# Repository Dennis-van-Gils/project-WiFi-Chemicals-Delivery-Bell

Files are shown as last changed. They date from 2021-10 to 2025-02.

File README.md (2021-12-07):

# WiFi Chemicals Delivery Bell

This project concerns an automated delivery notification system for when chemicals get delivered to our laboratory. Simply put, it is a box containing two huge arcade buttons which should get pressed by the deliverer: One for regular chemicals, and the other for temperature-critical (cooled) chemicals. All the deliverer has to do is push the appropriate button when having delivered chemicals. Once pushed, the buttons will light up and an email will be send to a configurable mailing list to inform everyone that chemicals are awaiting. There is also a web interface showing the current status, which you could check on your smartphone for instance. The buttons can be reset by pressing them again. This will revert the status to 'No chemicals awaiting' once more. 

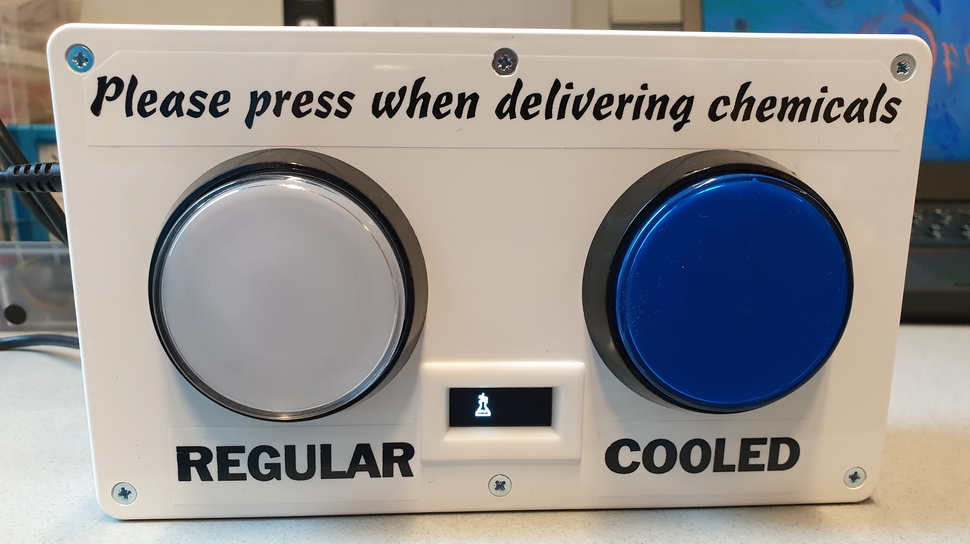
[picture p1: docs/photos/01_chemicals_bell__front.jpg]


The `Bell` is powered by a WiFi-enabled microprocessor board from Adafruit, namely an [Adafruit Feather HUZZAH ESP8266](https://www.adafruit.com/product/3046). This board sends out the button status over WiFi to a web server hosting the web interface. The web server also takes care of the emailing. An handy OLED screen on the `Bell` shows information regarding the WiFi connectivity, possible network errors, or when all is fine, an animation to inform the user about what it is doing. A 'flask' symbol indicates a happy idle state and an 'email' symbol indicates that an email will be send out within the coming minute. Repeatedly pressing the buttons will not cause massive email spam as there is this delay of one minute.

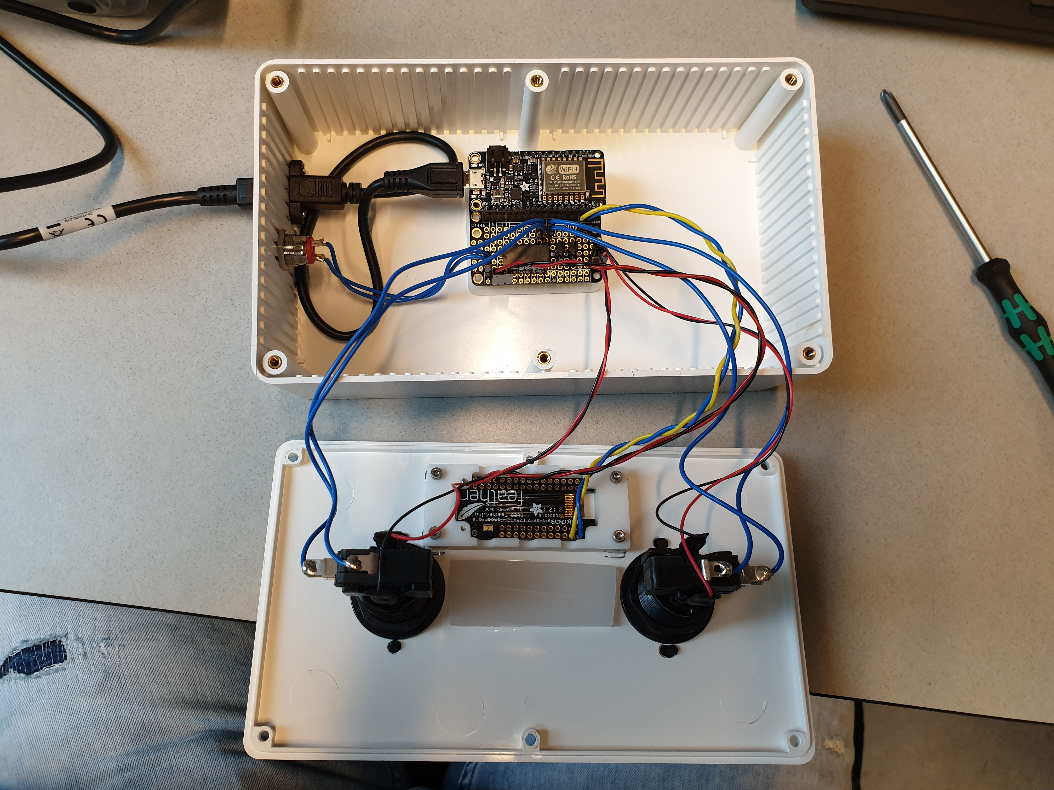
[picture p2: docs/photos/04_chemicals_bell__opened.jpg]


Detailed plans are included to build one yourself. The total parts cost of the enclosure plus electronics is around €130. The shopping lists are included (see below). A small amount of soldering is required. A few parts have to be 3D-printed, namely the OLED screen holder and the microcontroller board mounting plate (STL files included), but you could also [MacGyver](https://www.bbc.com/news/magazine-34075407) your own construction here.

I will gladly assist my colleagues at the University if they want to go live with the `Bell`. Setting up the web server is straight-forward. Simply copy the `web` folder to your server (presumably, the server that already is hosting your group's internet page) and edit the single configuration file `globals.php` to set up the email list and the hashed password used between the microcontroller and the server. The microcontroller itself needs to be flashed with firmware which has to be compiled. The source code for this is included in folder `source_mcu` and it has one configuration file you should edit: `source_mcu/src/wifi_settings_template.h`. If you send me your configuration file, I can also easily compile the firmware for you. 

Specific to the University of Twente: Each WiFi microcontroller has a unique MAC address which has to get registrered by LISA in order to get access to the Internet-of-Things network of the University. The microcontroller itself is firewalled by LISA from any incoming traffic.

## Web interface

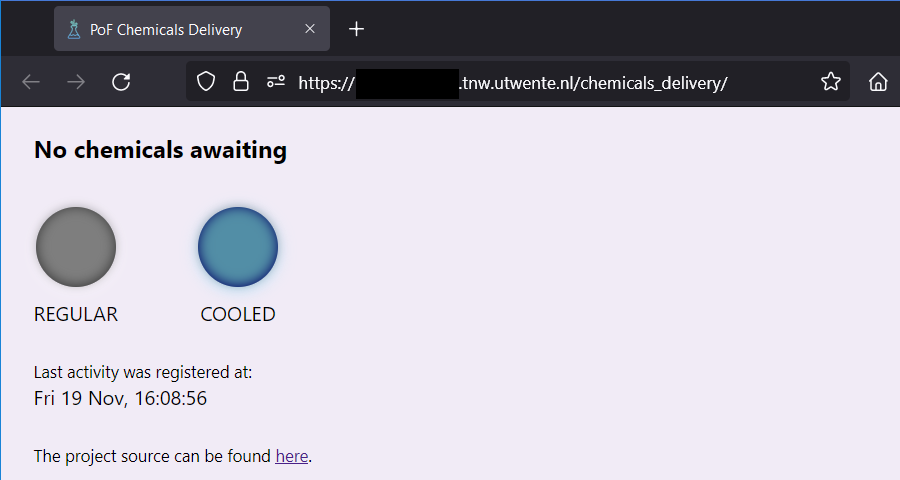
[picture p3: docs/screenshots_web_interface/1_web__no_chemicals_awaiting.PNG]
Web interface

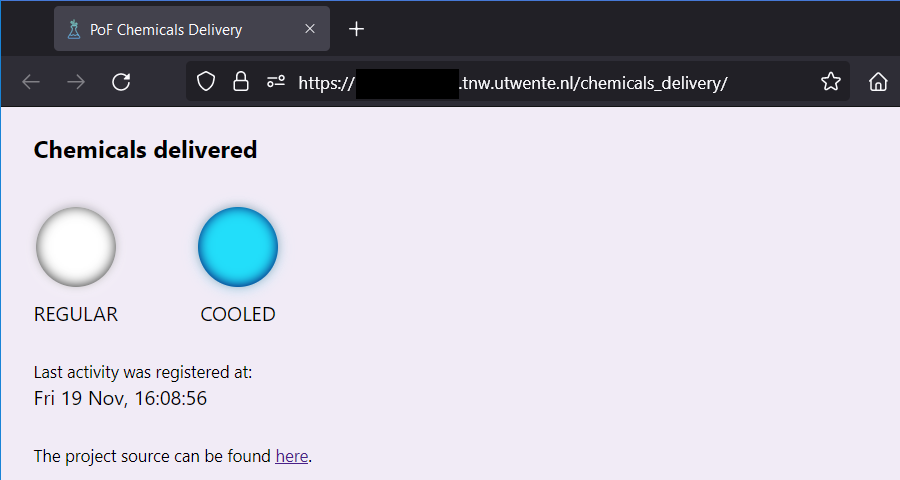
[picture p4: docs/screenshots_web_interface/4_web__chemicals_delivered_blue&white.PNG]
Web interface


## Design

[Solidworks 3D PDF](/Solidworks/_WiFi_Chemicals_Delivery_Bell.pdf)

[Electronic diagram](/docs/electronics/electronic_diagram.pdf)

## Soldering templates

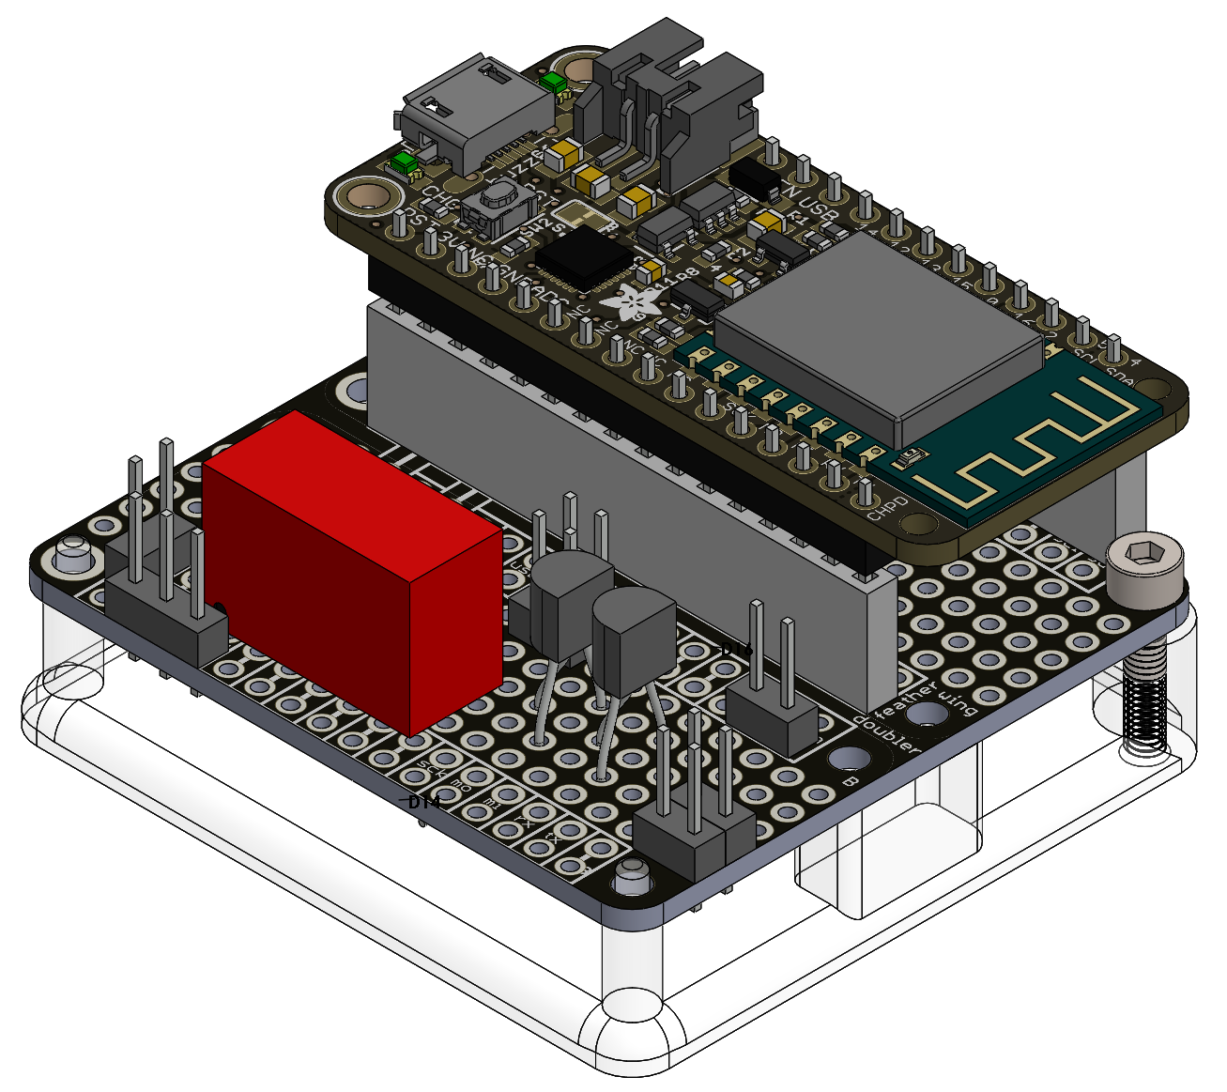
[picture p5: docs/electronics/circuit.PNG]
Soldering template 3D

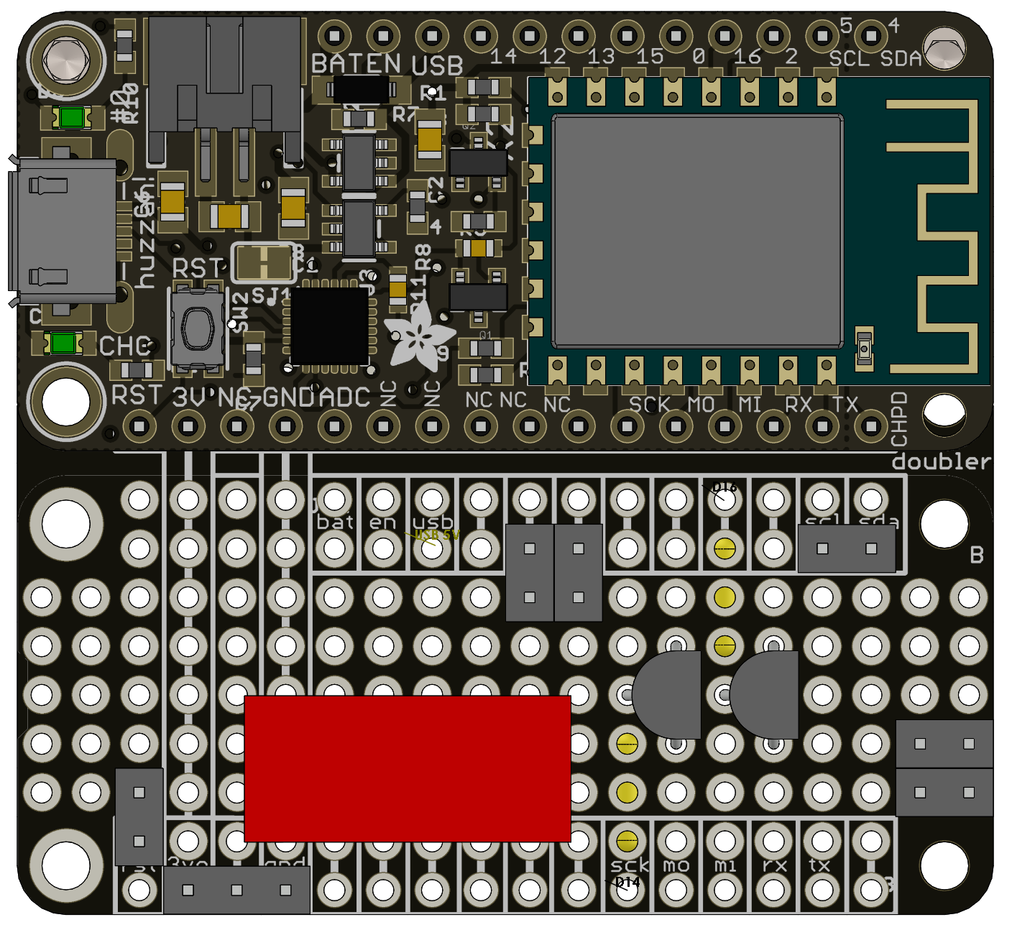
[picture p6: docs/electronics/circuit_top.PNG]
Soldering template top

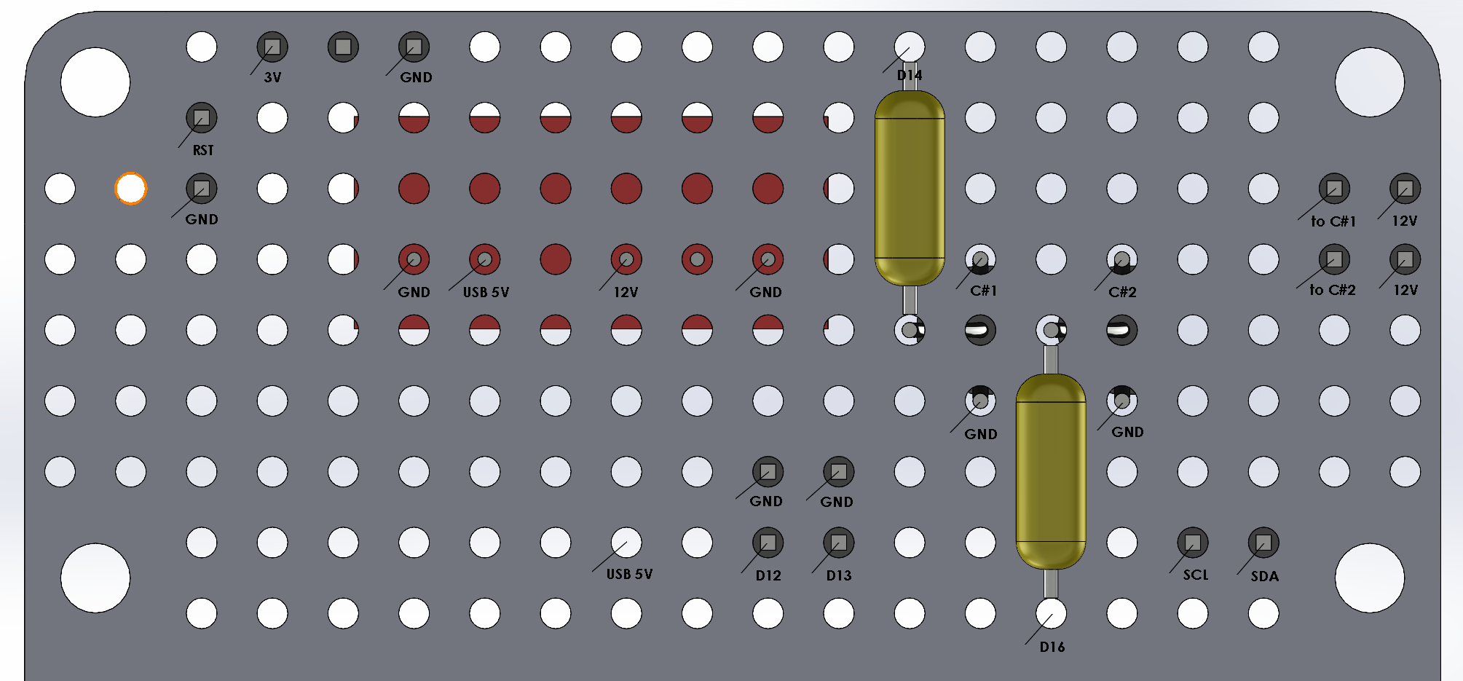
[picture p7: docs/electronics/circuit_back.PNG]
Soldering template back

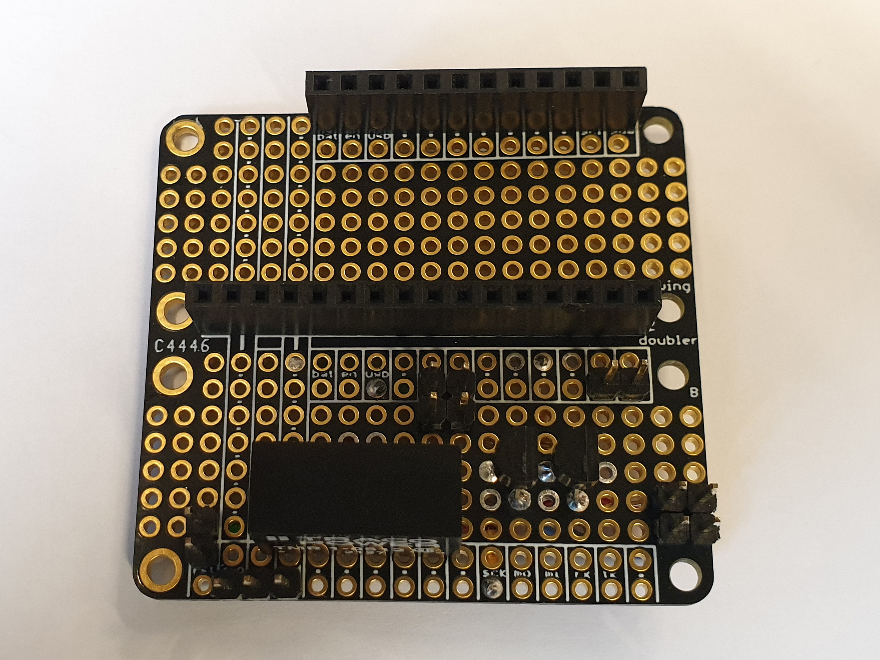
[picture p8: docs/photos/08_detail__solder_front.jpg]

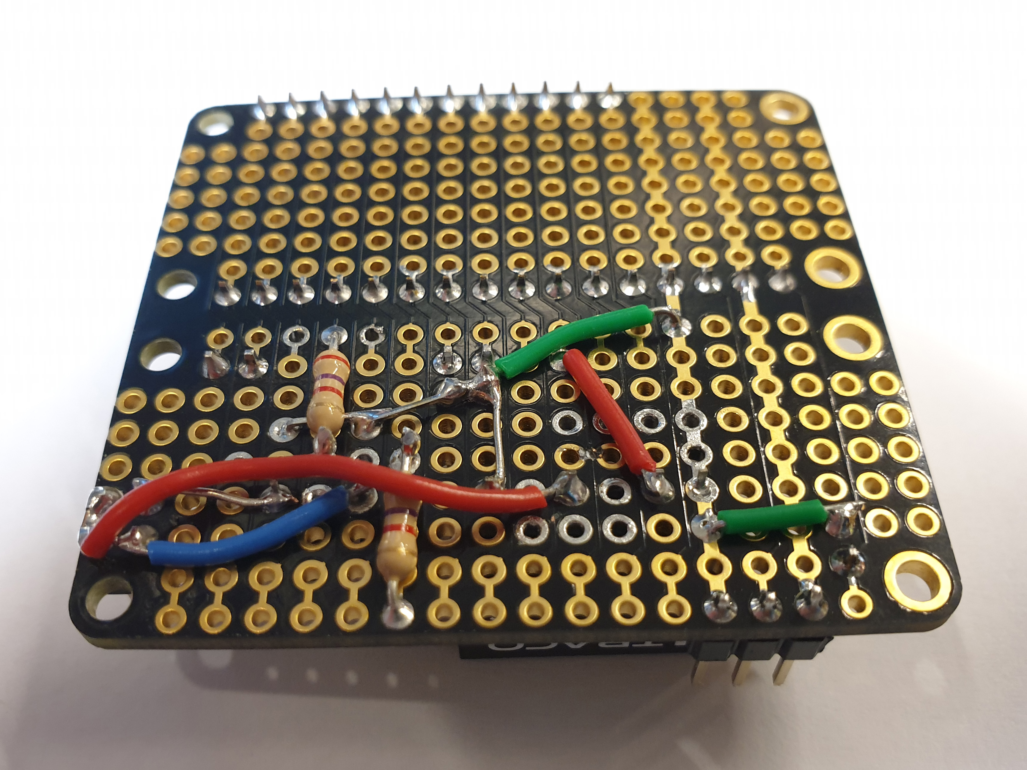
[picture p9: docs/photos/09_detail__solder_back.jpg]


## Shopping cart

[Shopping cart Farnell](/docs/shopping/_shopping_cart_Farnell.pdf)

[Shopping cart Kiwi Electronics](/docs/shopping/_shopping_cart_Kiwi_Electronics.pdf)

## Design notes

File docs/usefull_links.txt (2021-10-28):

CSS LED Lights                                                            https://codepen.io/fskirschbaum/pen/MYJNaj

How To HTTP GET and POST requests with ESP8266 - ESP8266 Shop             https://esp8266-shop.com/blog/how-to-http-get-and-post-requests-with-esp8266/

The Smallest WiFi Button in the World (ESP8266, MQTT, IFTTT) - YouTube    https://www.youtube.com/watch?v=ImVK5cGVrpQ

web page hot reload in plain JavaScript + Apache & PHP ← ABrandao.com     http://www.abrandao.com/2019/04/web-page-hot-reload-in-plain-javascript-php/

https://randomnerdtutorials.com/esp8266-nodemcu-http-get-post-arduino/
https://forum.arduino.cc/t/esp8266-httpclient-library-for-https/495245
https://maakbaas.com/esp8266-iot-framework/logs/https-requests/

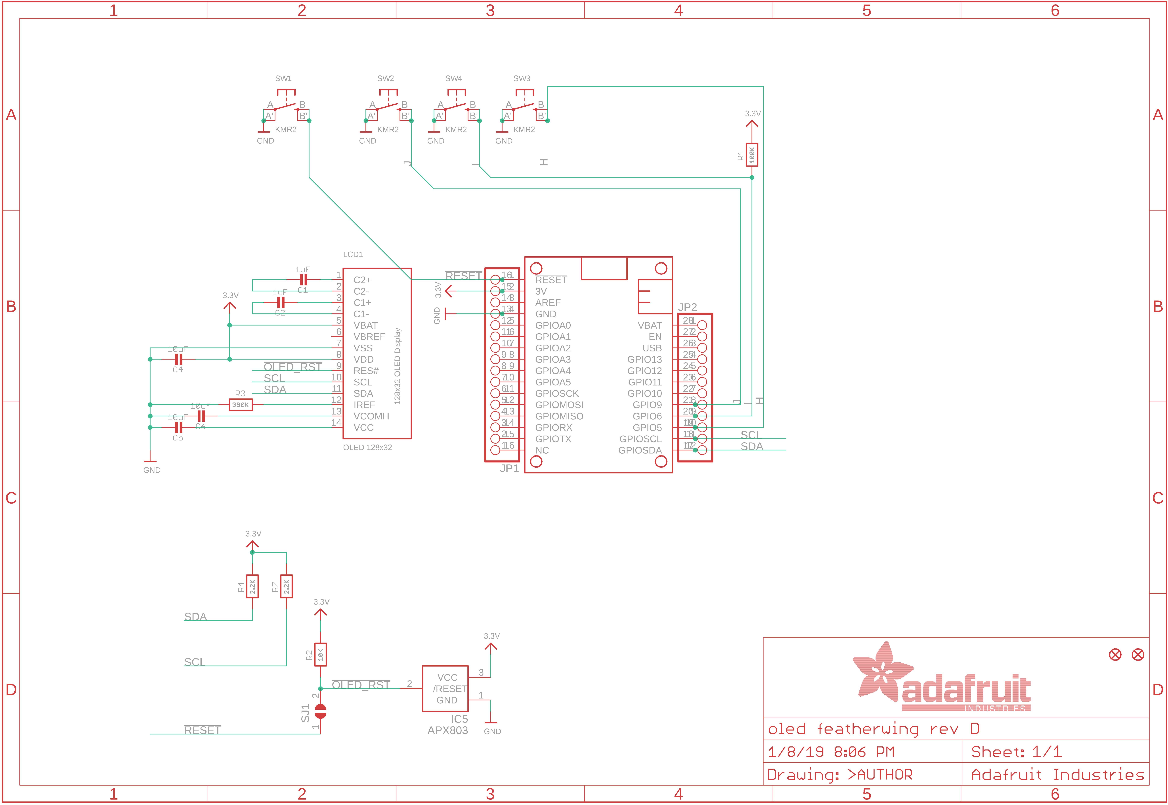
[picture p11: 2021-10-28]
docs/electronics/adafruit_products_Adafruit_OLED_FeatherWing_Sch.png

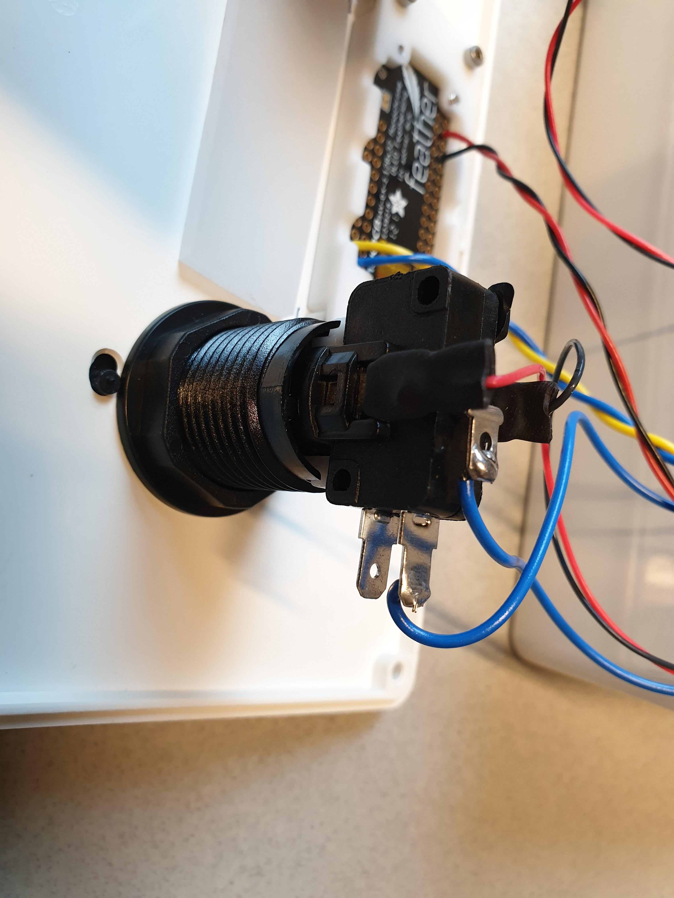
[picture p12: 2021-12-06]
docs/photos/06_detail__button.jpg

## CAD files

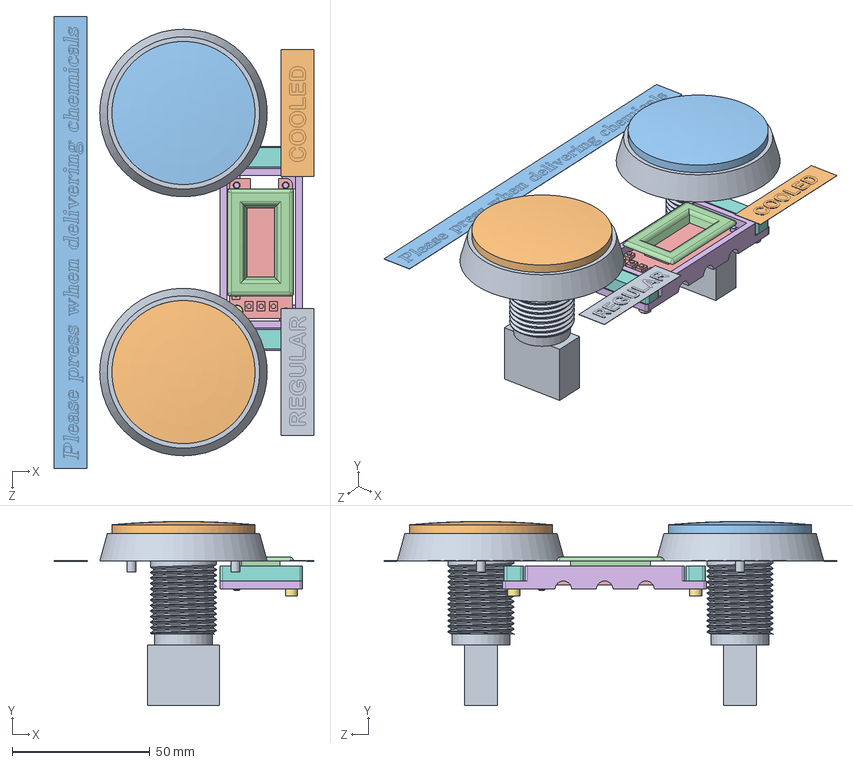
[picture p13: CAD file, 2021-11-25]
Solidworks/Camdenboss_BIM2006_16/bim2006_16_case_top.SLDASM
94.3 x 66.8 x 164.0 mm
arcade_button_60mm x 2
arcade_button_60mm_white
arcade_button_60mm_blue
3D_printed_OLED_bezel
2900 Feather OLED Wing
3D_printed_OLED_tray_part_1
ISO 4762 M2.5 x 6 - 6N x 3
3D_printed_OLED_tray_part_2 x 2
label_REGULAR
label_COOLED
label_header

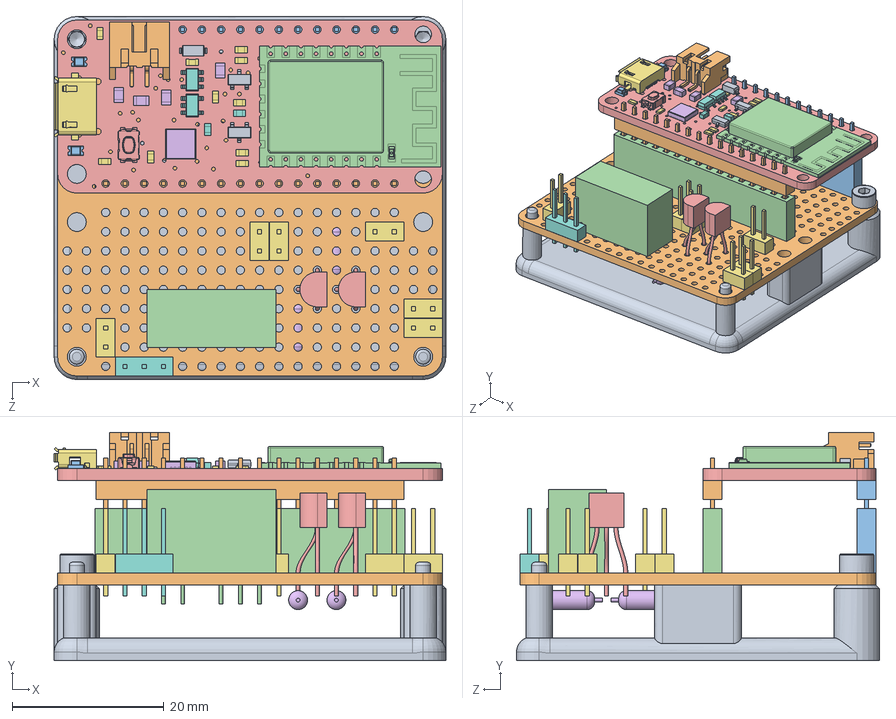
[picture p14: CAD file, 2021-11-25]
Solidworks/circuit_board_assy.SLDASM
51.7 x 30.2 x 47.9 mm
2890 Doubler FeatherWing
header_f12
header_f16
Board^PCB Component_2821 Adafruit ESP8266 Feather(2)_2821 Adafruit ESP8266 Feather
10uF^PCB Component_2821 Adafruit ESP8266 Feather(2)_2821 Adafruit ESP8266 Feather x 4
10K^PCB Component_2821 Adafruit ESP8266 Feather(2)_2821 Adafruit ESP8266 Feather x 10
MCP73831T-2ACI_OT^PCB Component_2821 Adafruit ESP8266 Feather(2)_2821 Adafruit ESP8266 Feather x 2
MBR120^PCB Component_2821 Adafruit ESP8266 Feather(2)_2821 Adafruit ESP8266 Feather
JSTPH^PCB Component_2821 Adafruit ESP8266 Feather(2)_2821 Adafruit ESP8266 Feather
RED^PCB Component_2821 Adafruit ESP8266 Feather(2)_2821 Adafruit ESP8266 Feather x 2
ESP-12^PCB Component_2821 Adafruit ESP8266 Feather(2)_2821 Adafruit ESP8266 Feather
KMR2^PCB Component_2821 Adafruit ESP8266 Feather(2)_2821 Adafruit ESP8266 Feather
CP2104^PCB Component_2821 Adafruit ESP8266 Feather(2)_2821 Adafruit ESP8266 Feather
20329^PCB Component_2821 Adafruit ESP8266 Feather(2)_2821 Adafruit ESP8266 Feather
1K^PCB Component_2821 Adafruit ESP8266 Feather(2)_2821 Adafruit ESP8266 Feather x 2
mmbt2222^PCB Component_2821 Adafruit ESP8266 Feather(2)_2821 Adafruit ESP8266 Feather x 2
header_m16
header_m12
Traco TMR 1-0512
transistor_TO92 x 2
resistor_250mW x 2
header_m2 x 6
header_m3
3D_printed_FeatherWing_doubler_mount
ISO 4762 M2.5 x 6 - 6N x 2

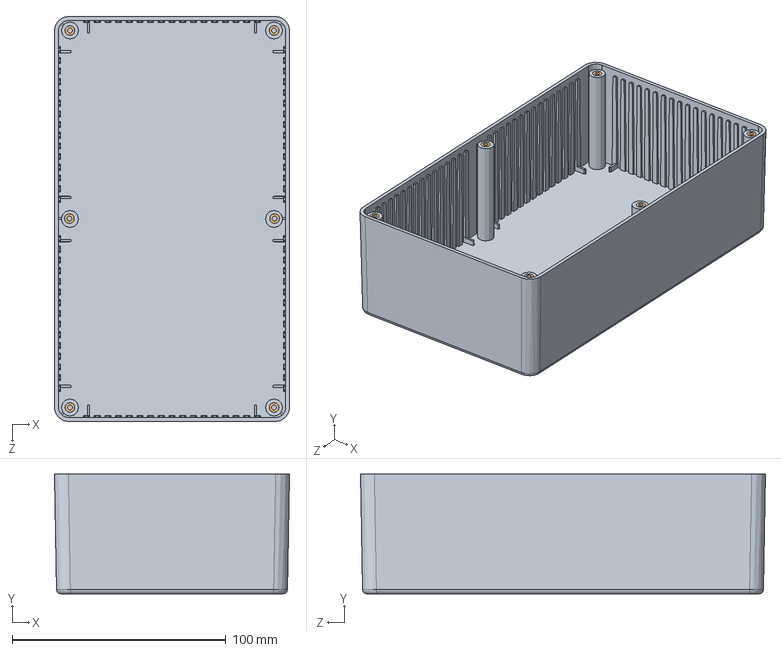
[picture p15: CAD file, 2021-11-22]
Solidworks/Camdenboss_BIM2006_16/bim2006_case_bottom.SLDASM
110.0 x 56.0 x 189.5 mm
bim2006_case_bottom
insert x 6

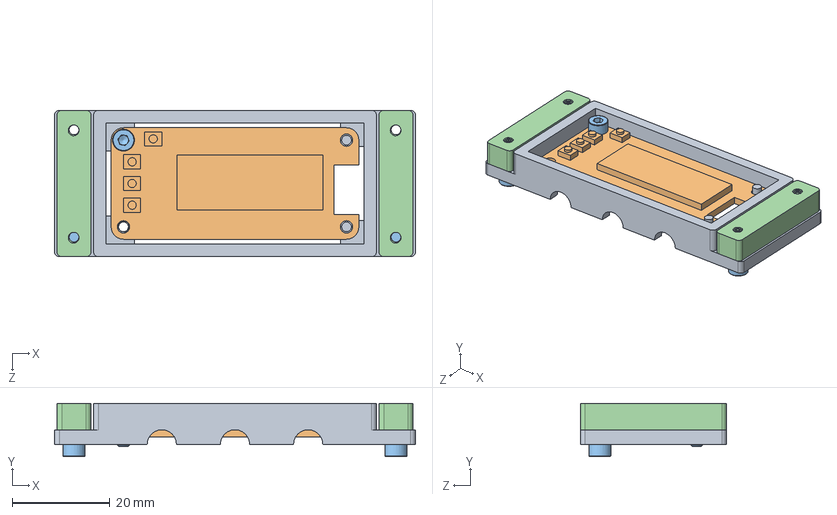
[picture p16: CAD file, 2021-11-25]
Solidworks/OLED_screen_in_tray.SLDASM
74.0 x 10.9 x 30.0 mm
2900 Feather OLED Wing
3D_printed_OLED_tray_part_1
ISO 4762 M2.5 x 6 - 6N x 3
3D_printed_OLED_tray_part_2 x 2

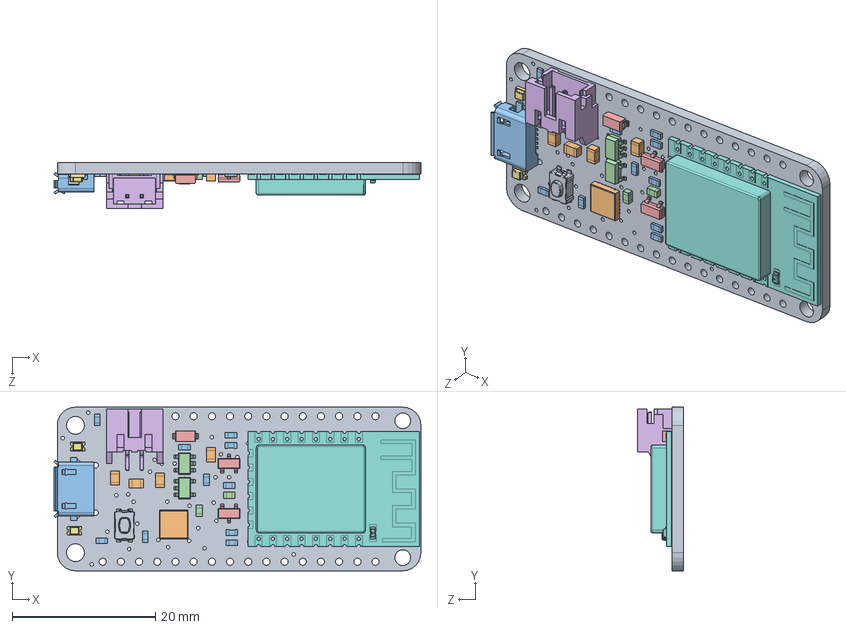
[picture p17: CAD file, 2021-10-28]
Solidworks/2821 Adafruit ESP8266 Feather.SLDASM
51.3 x 22.9 x 6.37 mm
Board^PCB Component_2821 Adafruit ESP8266 Feather(2)_2821 Adafruit ESP8266 Feather
10uF^PCB Component_2821 Adafruit ESP8266 Feather(2)_2821 Adafruit ESP8266 Feather x 4
10K^PCB Component_2821 Adafruit ESP8266 Feather(2)_2821 Adafruit ESP8266 Feather x 10
MCP73831T-2ACI_OT^PCB Component_2821 Adafruit ESP8266 Feather(2)_2821 Adafruit ESP8266 Feather x 2
MBR120^PCB Component_2821 Adafruit ESP8266 Feather(2)_2821 Adafruit ESP8266 Feather
JSTPH^PCB Component_2821 Adafruit ESP8266 Feather(2)_2821 Adafruit ESP8266 Feather
RED^PCB Component_2821 Adafruit ESP8266 Feather(2)_2821 Adafruit ESP8266 Feather x 2
ESP-12^PCB Component_2821 Adafruit ESP8266 Feather(2)_2821 Adafruit ESP8266 Feather
KMR2^PCB Component_2821 Adafruit ESP8266 Feather(2)_2821 Adafruit ESP8266 Feather
CP2104^PCB Component_2821 Adafruit ESP8266 Feather(2)_2821 Adafruit ESP8266 Feather
20329^PCB Component_2821 Adafruit ESP8266 Feather(2)_2821 Adafruit ESP8266 Feather
1K^PCB Component_2821 Adafruit ESP8266 Feather(2)_2821 Adafruit ESP8266 Feather x 2
mmbt2222^PCB Component_2821 Adafruit ESP8266 Feather(2)_2821 Adafruit ESP8266 Feather x 2

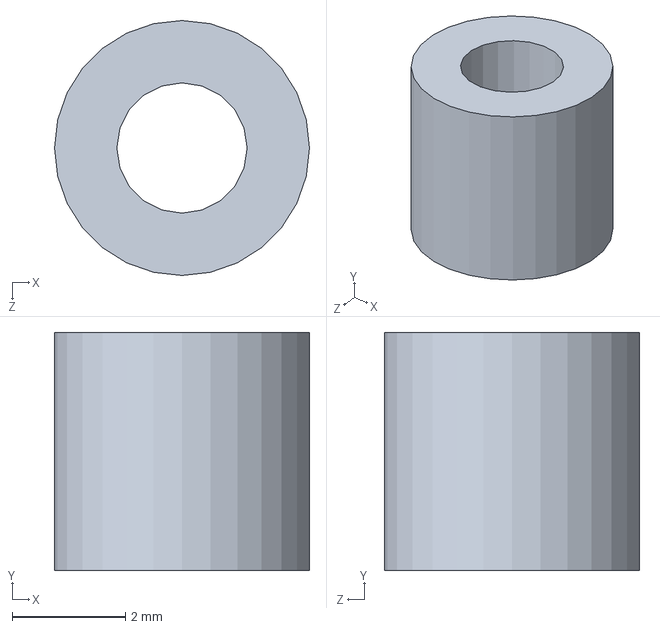
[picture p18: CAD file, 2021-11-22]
Solidworks/Camdenboss_BIM2006_16/insert.SLDPRT
4.50 x 4.20 x 4.50 mm

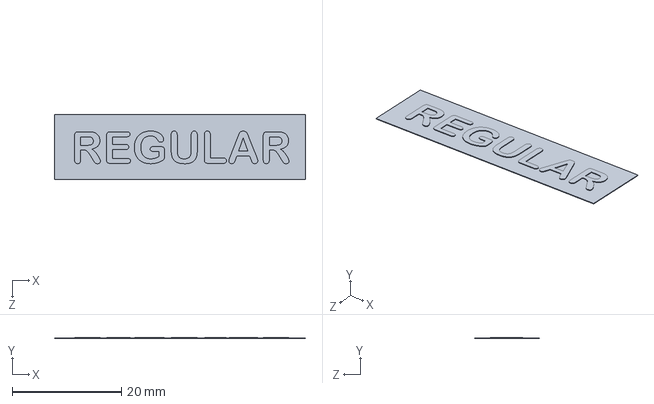
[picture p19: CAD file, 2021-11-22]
Solidworks/label_REGULAR.SLDPRT
46.0 x 0.2 x 12.0 mm

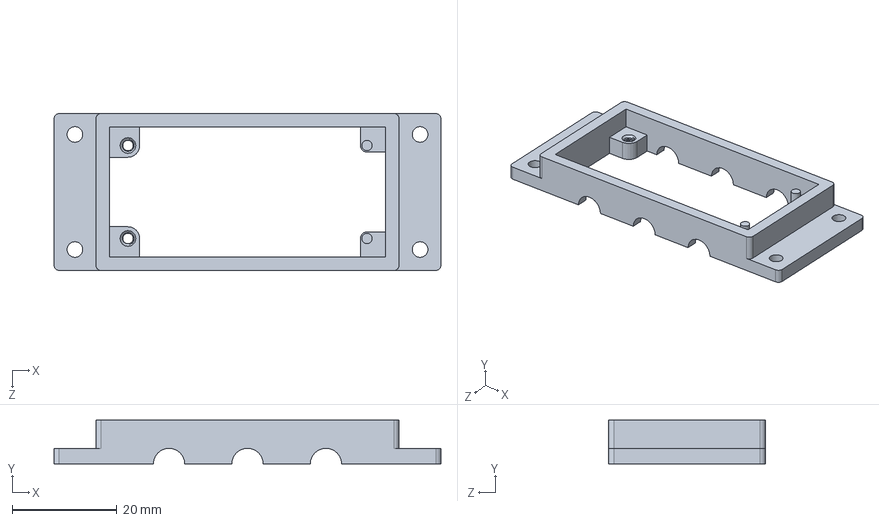
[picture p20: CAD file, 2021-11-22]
Solidworks/3D_printed_OLED_tray_part_1.SLDPRT
74.0 x 8.40 x 30.0 mm

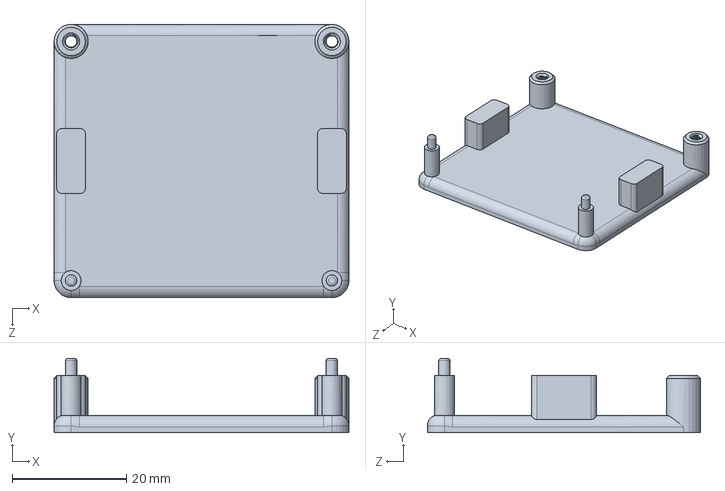
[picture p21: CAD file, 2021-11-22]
Solidworks/3D_printed_FeatherWing_doubler_mount.SLDPRT
51.7 x 13.0 x 47.9 mm

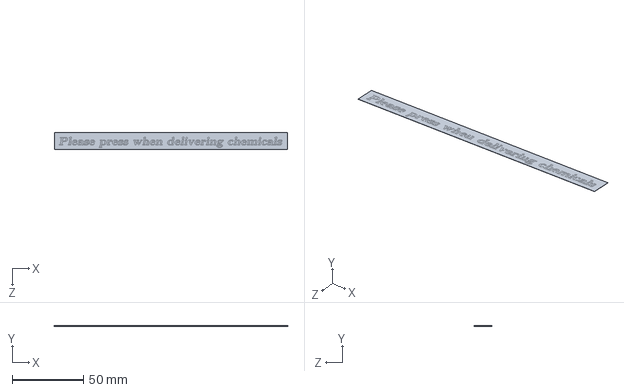
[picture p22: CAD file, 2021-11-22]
Solidworks/label_header.SLDPRT
164.0 x 0.1 x 12.0 mm

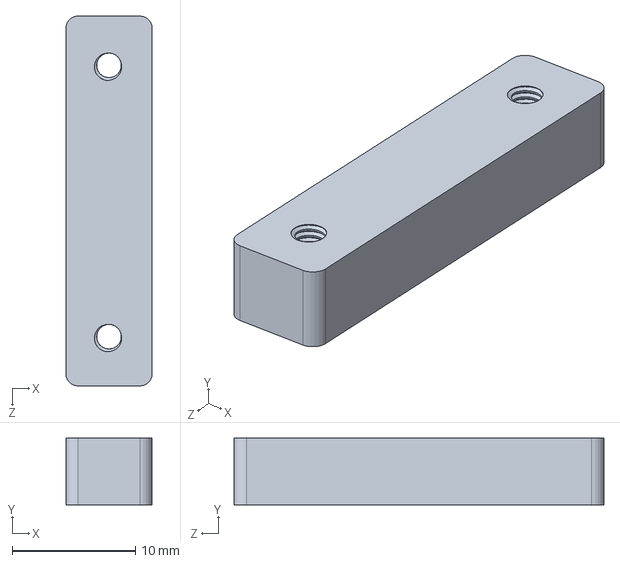
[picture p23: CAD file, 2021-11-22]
Solidworks/3D_printed_OLED_tray_part_2.SLDPRT
7.00 x 5.40 x 30.0 mm

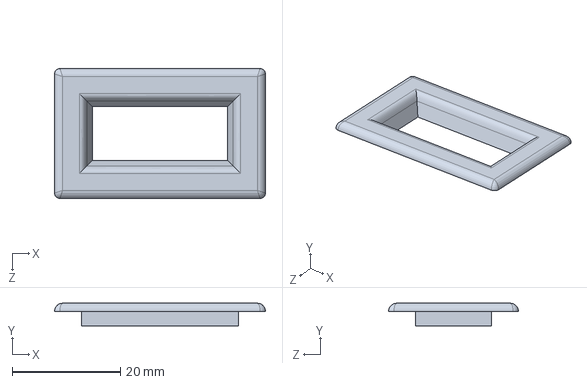
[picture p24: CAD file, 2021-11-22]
Solidworks/3D_printed_OLED_bezel.SLDPRT
39.0 x 4.20 x 24.0 mm

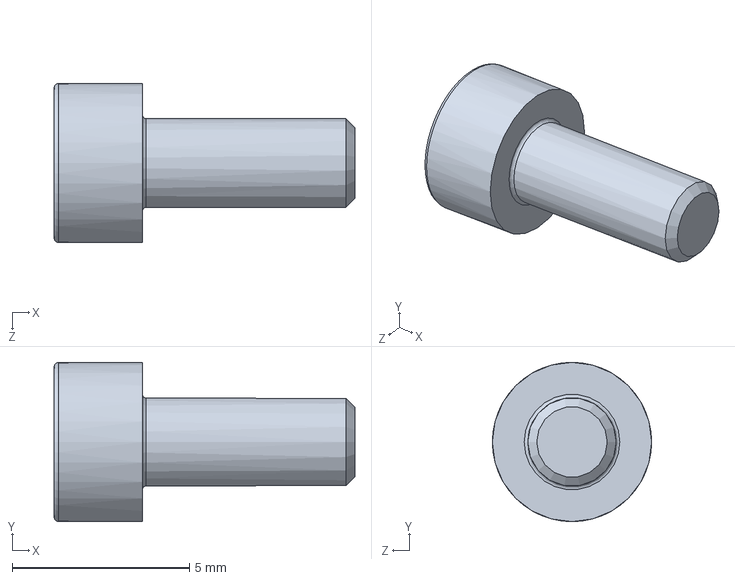
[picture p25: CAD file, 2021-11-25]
Solidworks/ISO 4762 M2.5 x 6 - 6N.SLDPRT
8.50 x 4.50 x 4.50 mm

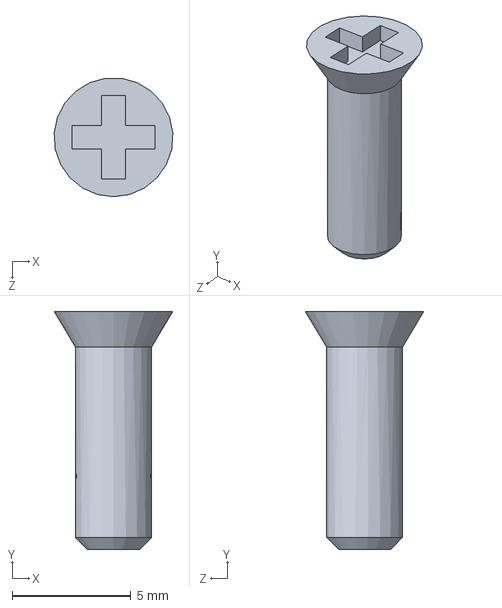
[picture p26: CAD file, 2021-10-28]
Solidworks/Camdenboss_BIM2006_16/screw.SLDPRT
4.99 x 10.0 x 4.98 mm

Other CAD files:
Solidworks/label_COOLED.SLDPRT
Solidworks/3D_printed_FeatherWing_doubler_mount.STL
Solidworks/3D_printed_OLED_bezel.STL
Solidworks/3D_printed_OLED_tray_part_1.STL
Solidworks/3D_printed_OLED_tray_part_2.STL
Solidworks/Camdenboss_BIM2006_16/bim2006_16_case_top.DXF
Solidworks/Camdenboss_BIM2006_16/bim2006_16_case_top.SLDDRW
Solidworks/Camdenboss_BIM2006_16/bim2006_16_case_top.SLDPRT
Solidworks/Camdenboss_BIM2006_16/bim2006_case_bottom.SLDPRT

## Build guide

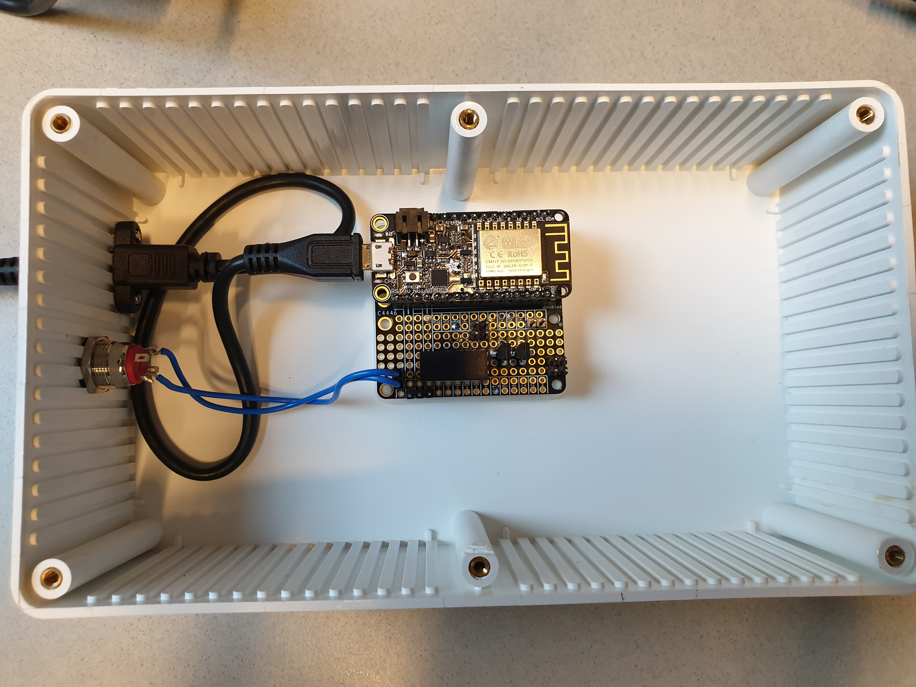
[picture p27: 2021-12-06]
docs/photos/14_assembly.jpg

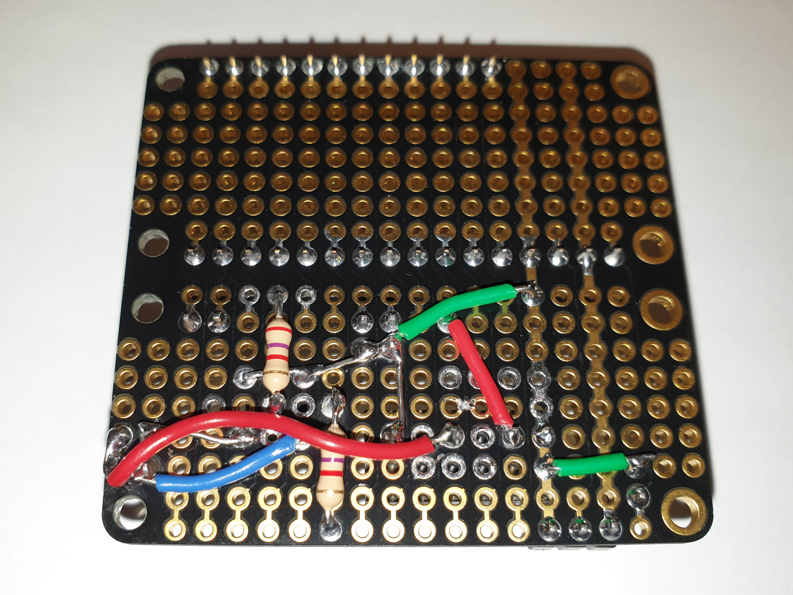
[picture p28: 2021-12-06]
docs/photos/10_detail__solder_back.jpg

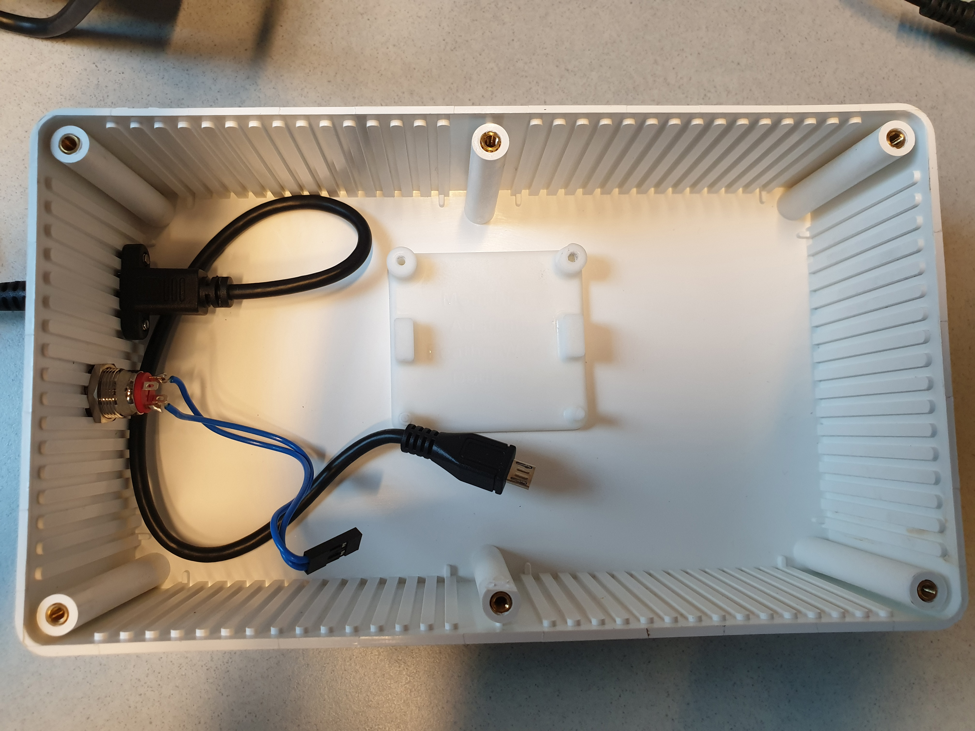
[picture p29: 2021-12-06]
docs/photos/11_assembly.jpg

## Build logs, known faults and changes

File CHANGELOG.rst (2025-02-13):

Changelog
=========

4.0.0 (2025-02-13)
------------------
Keep track of the last sent email and print this info to the webpage.

3.0.0 (2025-02-13)
------------------
Symfony Framework is now used to send out notification emails, instead of using
the native PHP `mail()` method. You must now make sure to install Symfony using
Composer onto your PHP server.

2.0.0 (2024-11-06)
------------------
After the automated 'Chemicals delivered' email has been send to the user,
revert all buttons back to their idle off state. The user no longer has to
deactivate any lit buttons, and hence the 'All done' email message is now
suppressed.

1.0.0 (2021-10-28)
------------------
* Initial release

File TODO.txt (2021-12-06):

---------------
  Project
---------------

All done

---------------
  Web
---------------

All done

---------------
  MCU
---------------

All done

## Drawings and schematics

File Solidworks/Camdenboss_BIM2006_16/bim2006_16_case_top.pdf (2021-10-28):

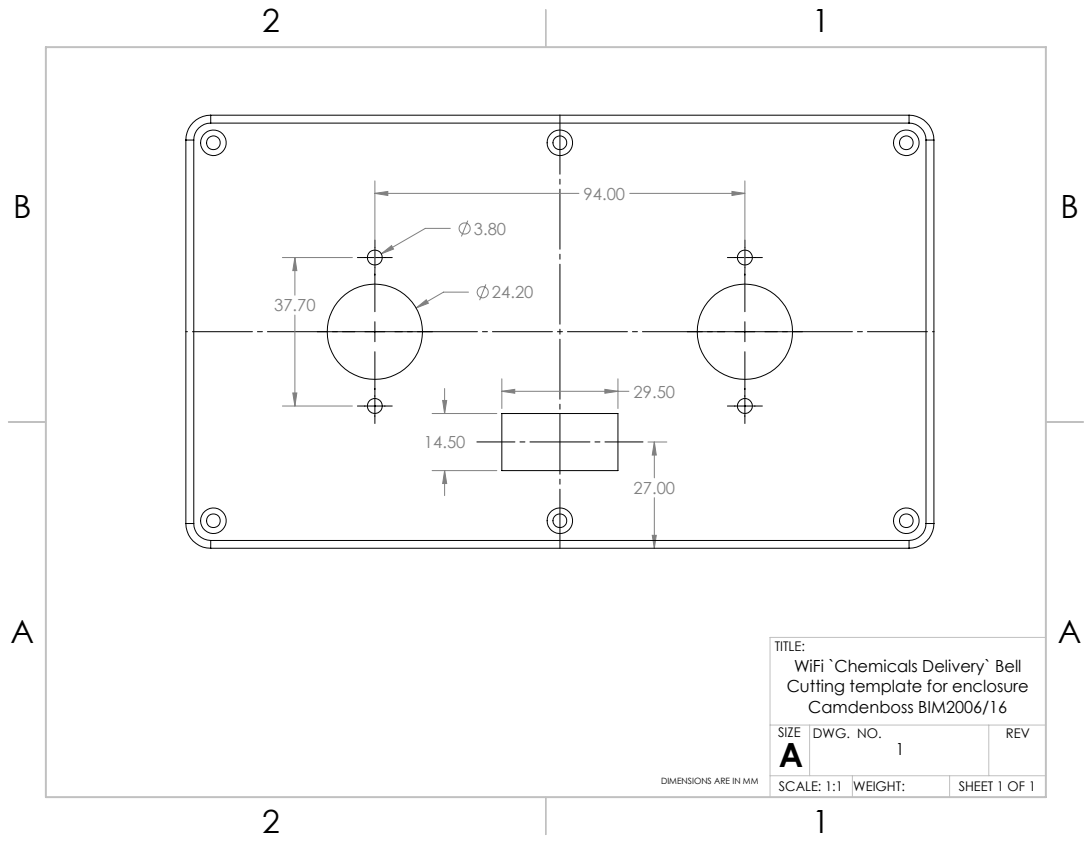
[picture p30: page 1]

TITLE:
WiFi `Chemicals Delivery` Bell
Cutting template for enclosure
Camdenboss BIM2006/16

SIZE A | DWG. NO. 1 | REV

DIMENSIONS ARE IN MM

SCALE: 1:1 | WEIGHT: | SHEET 1 OF 1

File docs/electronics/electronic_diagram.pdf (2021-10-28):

### title : Electronic diagram `WiFi Chemicals Delivery Bell` author : Dennis van Gils

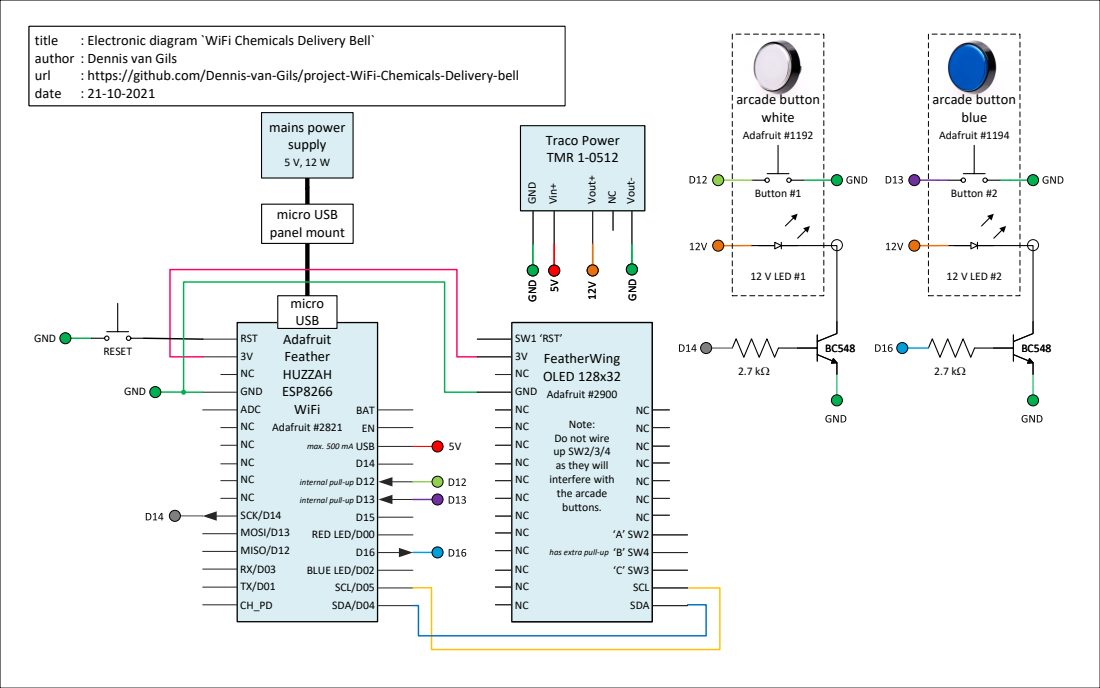
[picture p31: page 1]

author : Dennis van Gils

has extra pull-up

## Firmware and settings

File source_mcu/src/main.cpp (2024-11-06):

/*
WiFi Chemicals Delivery Bell

Hardware:
  Adafruit Feather HUZZAH with ESP8266 (Adafruit #3046)
  Adafruit FeatherWing OLED - 128x32 OLED  (Adafruit #2900)

This project uses the following code editor:
  Microsoft Visual Studio Code with plugin PLATFORMIO

NOTE:
  You must create a file called `wifi_settings.h` that should contain the user
  variables specific to your WiFi network, password and webpage script
  locations. You can use the provided template `wifi_settings_template.h` which
  you fill out and save as `wifi_settings.h`. You need to compile and upload
  this source code to the Arduino whenever you make changes to it.

GitHub: https://github.com/Dennis-van-Gils/project-WiFi-Chemicals-Delivery-Bell
Author: Dennis van Gils
Date  : 06-11-2024
 */

#include <Arduino.h>
#include <SPI.h>
#include <Wire.h>

#include <ESP8266HTTPClient.h>
#include <ESP8266WiFi.h>
#include <WiFiClientSecure.h>

#include <Adafruit_GFX.h>
#include <Adafruit_I2CDevice.h>
#include <Adafruit_SSD1306.h>
#include <avdweb_Switch.h>

#include <DvG_SerialCommand.h>
#include <StringReserveCheck.h>

#if __has_include("wifi_settings.h")
#include <wifi_settings.h>
#else
#include <wifi_settings_template.h>
#endif

// Serial monitor
#define Ser Serial
DvG_SerialCommand sc(Ser);

// String buffer for outgoing message
#define MSG_LEN 128
char msg[MSG_LEN] = {"\0"};

// Network vars
#define WIFI_BEGIN_TIMEOUT 30 // Stop trying to connect after N seconds [s]
char wifi_status_descr[16] = {"\0"};
wl_status_t wifi_status;

// Prevent String() from fragmenting the heap
// https://www.forward.com.au/pfod/ArduinoProgramming/ArduinoStrings/index.html#reboot
// https://www.instructables.com/Taming-Arduino-Strings-How-to-Avoid-Memory-Issues/
String http_payload;
StringReserveCheck http_payload_SRC;
String http_request;
StringReserveCheck http_request_SRC;
String ip_address;
StringReserveCheck ip_address_SRC;
String mac_address;
StringReserveCheck mac_address_SRC;

// Switches
#define PIN_BUTTON_SWITCH_WHITE 12
#define PIN_BUTTON_SWITCH_BLUE 13
Switch switch_white = Switch(PIN_BUTTON_SWITCH_WHITE, INPUT_PULLUP);
Switch switch_blue = Switch(PIN_BUTTON_SWITCH_BLUE, INPUT_PULLUP);

// LEDs
#define PIN_ONBOARD_LED_RED 0  // Inverted. Will mimick the white button LED
#define PIN_ONBOARD_LED_BLUE 2 // Inverted. Will mimick the blue button LED
#define PIN_BUTTON_LED_WHITE 14
#define PIN_BUTTON_LED_BLUE 16

void write_LED_white(bool state) {
  digitalWrite(PIN_BUTTON_LED_WHITE, state);
  digitalWrite(PIN_ONBOARD_LED_RED, !state); // Mimick white button LED
}

void write_LED_blue(bool state) {
  digitalWrite(PIN_BUTTON_LED_BLUE, state);
  digitalWrite(PIN_ONBOARD_LED_BLUE, !state); // Mimick blue button LED
}

// Request to turn LEDs on or off. Will be granted if the communication with the
// web server was successful. This ensures that both the Arduino and web server
// side show the same LED states.
static bool request_is_pending;
static bool request_LED_white; // True: Turn on, False: Turn off.
static bool request_LED_blue;  // True: Turn on, False: Turn off.

// Granted LED states
static bool state_LED_white; // True: Turned on, False: Turned off.
static bool state_LED_blue;  // True: Turned on, False: Turned off.

// OLED display
Adafruit_SSD1306 display = Adafruit_SSD1306(128, 32, &Wire);

// https://diyusthad.com/image2cpp
// Bitmap: 'Flask', 32x32px
const uint8_t img_flask[] PROGMEM = {
    0x00, 0x01, 0x80, 0x00, 0x00, 0x01, 0x80, 0x00, 0x00, 0x01, 0x80, 0x00,
    0x00, 0x1d, 0x80, 0x00, 0x00, 0x3f, 0x80, 0x00, 0x00, 0x3f, 0xb8, 0x00,
    0x00, 0x3f, 0xfc, 0x00, 0x00, 0x1f, 0xfc, 0x00, 0x00, 0x07, 0xfc, 0x00,
    0x00, 0x07, 0xfc, 0x00, 0x00, 0x1f, 0xf8, 0x00, 0x00, 0x3f, 0xfc, 0x00,
    0x00, 0x38, 0x1c, 0x00, 0x00, 0x3c, 0x3c, 0x00, 0x00, 0x1c, 0x38, 0x00,
    0x00, 0x0c, 0x30, 0x00, 0x00, 0x0c, 0x30, 0x00, 0x00, 0x0c, 0x30, 0x00,
    0x00, 0x0c, 0x30, 0x00, 0x00, 0x1c, 0x38, 0x00, 0x00, 0x18, 0x18, 0x00,
    0x00, 0x38, 0x1c, 0x00, 0x00, 0x70, 0x0e, 0x00, 0x00, 0x70, 0x0e, 0x00,
    0x00, 0xe7, 0x9f, 0x00, 0x01, 0xff, 0xff, 0x80, 0x01, 0xff, 0xf7, 0x80,
    0x03, 0x98, 0x61, 0xc0, 0x03, 0x80, 0x01, 0xc0, 0x03, 0x00, 0x00, 0xc0,
    0x03, 0xff, 0xff, 0xc0, 0x03, 0xff, 0xff, 0xc0};

// Bitmap: 'Email', 32x32px
const uint8_t img_email[] PROGMEM = {
    0xff, 0xff, 0xff, 0xff, 0xff, 0xff, 0xff, 0xff, 0xff, 0xff, 0xff, 0xff,
    0xff, 0xff, 0xff, 0xff, 0xff, 0xff, 0xff, 0xff, 0xff, 0xff, 0xff, 0xff,
    0xf0, 0x00, 0x00, 0x0f, 0xe7, 0xff, 0xff, 0xe7, 0xe3, 0xff, 0xff, 0xc7,
    0xe9, 0xff, 0xff, 0x97, 0xec, 0xff, 0xff, 0x37, 0xee, 0x7f, 0xfe, 0x77,
    0xef, 0x3f, 0xfc, 0xf7, 0xef, 0x9f, 0xf9, 0xf7, 0xef, 0xcf, 0xf3, 0xf7,
    0xef, 0xe7, 0xe7, 0xf7, 0xef, 0xf3, 0xcf, 0xf7, 0xef, 0xf1, 0x8f, 0xf7,
    0xef, 0xec, 0x37, 0xf7, 0xef, 0xde, 0x7b, 0xf7, 0xef, 0xbf, 0xfd, 0xf7,
    0xef, 0x7f, 0xfe, 0xf7, 0xee, 0xff, 0xff, 0x77, 0xed, 0xff, 0xff, 0xb7,
    0xe1, 0xff, 0xff, 0x87, 0xf0, 0x00, 0x00, 0x0f, 0xff, 0xff, 0xff, 0xff,
    0xff, 0xff, 0xff, 0xff, 0xff, 0xff, 0xff, 0xff, 0xff, 0xff, 0xff, 0xff,
    0xff, 0xff, 0xff, 0xff, 0xff, 0xff, 0xff, 0xff};

// To construct full URLs from `wifi_settings.h`
const int URL_MAXLEN = 256;
char url_starting_up[URL_MAXLEN];
char url_button_pressed[URL_MAXLEN];
char url_send_email[URL_MAXLEN];

/*------------------------------------------------------------------------------
  EmailScheduler
------------------------------------------------------------------------------*/

class EmailScheduler {
private:
  uint32_t T_delay = EMAIL_DELAY_MINUTES * 60 * 1e3;
  uint32_t last_bump;

  // Legacy LED states
  // These states are used to detect a change over a long (1 minute) interval
  // before an email will be send out. This allows the user to revert back an
  // (erroneous) button push and prevents an email from being send out if the
  // state has reverted to its `legacy` state in the mean time. Prevents spam.
  bool legacy_state_LED_white;
  bool legacy_state_LED_blue;

public:
  bool pending_email;

  EmailScheduler() { reset(); }

  void reset() {
    last_bump = millis();
    pending_email = false;
    legacy_state_LED_white = state_LED_white;
    legacy_state_LED_blue = state_LED_blue;
  }

  void bump() {
    if ((legacy_state_LED_white == state_LED_white) &
        (legacy_state_LED_blue == state_LED_blue)) {
      pending_email = false;
    } else {
      last_bump = millis();
      pending_email = true;
    }
    Ser.print("Email pending: ");
    Ser.println(pending_email ? "True\n" : "False\n");
  }

  bool poll() { return ((pending_email) & (millis() - last_bump > T_delay)); }
};

EmailScheduler email_scheduler;

/*------------------------------------------------------------------------------
  Screensaver
------------------------------------------------------------------------------*/

class Screensaver {
private:
  uint32_t T_wait;        // Screensaver shows after this period         [ms]
  uint16_t T_frame;       // Display period for each frame               [ms]
  uint32_t last_activity; // millis() value since last call to `reset()` [ms]
  uint32_t last_draw;     // millis() value since last frame draw        [ms]
  int16_t x_pos;          // Screensaver animation x-pixel position
  uint32_t now;

public:
  Screensaver(uint32_t wait_period_ms, uint16_t frame_period_ms) {
    // Args:
    //    wait_period_ms  (uint32_t): Show screensaver after this time [ms]
    //    frame_period_ms (uint16_t): Screensaver animation speed [ms]
    T_wait = wait_period_ms;
    T_frame = frame_period_ms;
    reset();
  }

  void reset() {
    // Reset the inactivity timer of the screensaver
    now = millis();
    last_activity = now;
    last_draw = now;
    x_pos = 0;
  }

  void engage(uint32_t delay = 0) {
    // Engage the screensaver after the passed delay [ms]
    now = millis();
    last_activity = now - T_wait + delay;
    last_draw = now - T_wait + delay;
    x_pos = 0;
  }

  void update() {
    // Draw screensaver to OLED screen when inactivity timer has fired,
    // otherwise leave the screen alone and continue waiting.
    now = millis();

    const uint8_t *img =
        (email_scheduler.pending_email ? img_email : img_flask);

    if ((now - last_activity > T_wait) & (now - last_draw > T_frame)) {
      // Scroll left-to-right
      display.clearDisplay();
      display.drawBitmap(x_pos, 0, img, 32, 32, WHITE);
      if (x_pos > 127 - 32) {
        display.drawBitmap(x_pos - 128, 0, img, 32, 32, WHITE);
      }
      if (++x_pos == 128) {
        x_pos = 0;
      }
      display.display();
      last_draw = now;
    }
  }
};

Screensaver screensaver(30000, 200);

/*------------------------------------------------------------------------------
  get_wifi_status_descr
------------------------------------------------------------------------------*/

// clang-format off
void get_wifi_status_descr(wl_status_t status, char descr[16]) {
  switch (status) {
    case WL_IDLE_STATUS    : snprintf(descr, 16, "%s", "IDLE_STATUS")    ; break;
    case WL_NO_SSID_AVAIL  : snprintf(descr, 16, "%s", "NO_SSID_AVAIL")  ; break;
    case WL_SCAN_COMPLETED : snprintf(descr, 16, "%s", "SCAN_COMPLETED") ; break;
    case WL_CONNECTED      : snprintf(descr, 16, "%s", "CONNECTED")      ; break;
    case WL_CONNECT_FAILED : snprintf(descr, 16, "%s", "CONNECT_FAILED") ; break;
    case WL_CONNECTION_LOST: snprintf(descr, 16, "%s", "CONNECTION_LOST"); break;
    case WL_WRONG_PASSWORD : snprintf(descr, 16, "%s", "WRONG_PASSWORD") ; break;
    case WL_DISCONNECTED   : snprintf(descr, 16, "%s", "DISCONNECTED")   ; break;
    default                : snprintf(descr, 16, "%s", "")               ; break;
  }
}
// clang-format on

/*------------------------------------------------------------------------------
  infinite_loop
------------------------------------------------------------------------------*/

void infinite_loop(const char *final_msg) {
  // Infinite loop without escape, while displaying a final error message on
  // the OLED screen flashing on and off to prevent OLED burn-in.
  bool toggle = true;
  Ser.println(final_msg);

  while (true) {
    display.clearDisplay();
    display.setCursor(0, 0);
    if (toggle) {
      display.print(final_msg);
      display.display();
      delay(2000);
    } else {
      display.display();
      delay(1000);
    }
    toggle = !toggle;
  }
}

/*------------------------------------------------------------------------------
  http_post
------------------------------------------------------------------------------*/

bool http_post(const String &url, const String &post_http_request,
               const String &post_expected_reply) {
  /* Send a HTTP POST request to the web server. Will handle errors and also
  checks for a correct POST reply. Shows info on the serial monitor and OLED
  display.

  Returns true when successful, otherwise false.
  */
  bool success = false;
  HTTPClient http;
  WiFiClientSecure client;
  int http_code;

  // yield();
  delay(1);

  wifi_status = WiFi.status();
  if (wifi_status == WL_CONNECTED) {
    Ser.println(F("Request"));
    Ser.print(F("  "));
    Ser.println(url);
    Ser.print(F("  "));
    Ser.println(post_http_request);

    client.setInsecure(); // Secure is overkill for our project
    http.begin(client, url);
    http.addHeader(F("Content-Type"), F("application/x-www-form-urlencoded"));

    http_code = http.POST(post_http_request);
    http_payload = http.getString();

    // yield();
    delay(1);

    Ser.println(F("Reply"));
    Ser.println(F("  \"\"\""));
    Ser.println(http_payload);
    Ser.println(F("  \"\"\""));

    if (http_code == 200) {
      if (strcmp(http_payload.c_str(), post_expected_reply.c_str()) == 0) {
        Ser.println(F("Success"));
        display.println(F("Success"));
        success = true;

      } else if (strcmp(http_payload.c_str(), "Invalid key") == 0) {
        Ser.println(F("SERVER ERROR: Invalid key received by web server."));
        Ser.println(F("See 'Globals.php' on the web server."));
        display.clearDisplay();
        display.setCursor(0, 0);
        display.print(F("SERVER ERR\nINVALIDKEY"));

      } else {
        Ser.println(F("SERVER ERROR: Unexpected reply from web server."));
        Ser.print(F("Was expecting: "));
        Ser.println(post_expected_reply);
        display.clearDisplay();
        display.setCursor(0, 0);
        display.print(F("SERVER ERR\nUNEXPREPLY"));
      }

    } else { // if (http_code == 200)
      Ser.print(F("HTTP ERROR "));
      Ser.println(http_code);
      display.clearDisplay();
      display.setCursor(0, 0);
      display.println(F("HTTP ERROR"));
      display.println(http_code);
    }

    http.end();

  } else { // if (wifi_status == WL_CONNECTED)
    // WiFi got disconnected
    // TODO: Try to reconnect?
    display.setTextSize(1);
    get_wifi_status_descr(wifi_status, wifi_status_descr);
    snprintf(msg, MSG_LEN, "WiFi disconnected:\n%s\nPress reset.",
             wifi_status_descr);
    infinite_loop(msg);
  }

  // yield();
  delay(1);

  Ser.println("");
  display.display();

  return success;
}

/*------------------------------------------------------------------------------
  send_starting_up
------------------------------------------------------------------------------*/

bool send_starting_up() {
  /* Signal the web server that the Arduino has (re)started.
  Returns true when successful, otherwise false.
   */
  display.clearDisplay();
  display.setCursor(0, 0);
  display.println(F("Sending..."));
  display.display();

  // Reset
  request_is_pending = false;
  request_LED_white = false;
  request_LED_blue = false;
  state_LED_white = false;
  state_LED_blue = false;
  write_LED_white(false);
  write_LED_blue(false);
  email_scheduler.reset();

  Ser.println(F("STARTING UP\n-----------"));
  http_request = F("key=");
  http_request += mac_address;
  bool success = http_post(url_starting_up, http_request, "1");

  screensaver.engage(success ? 1e3 : 30e3);
  return success;
}

/*------------------------------------------------------------------------------
  send_email
------------------------------------------------------------------------------*/

bool send_email(bool restarted = false) {
  /* Signal the web server to send out emails.
  Returns true when successful, otherwise false.
   */
  display.clearDisplay();
  display.setCursor(0, 0);
  display.println(F("Emailing.."));
  display.display();

  Ser.println(F("EMAIL\n-----"));
  http_request = F("key=");
  http_request += mac_address;
  bool success = http_post(url_send_email, http_request, "1");

  screensaver.engage(success ? 1e3 : 30e3);
  return success;
}

/*------------------------------------------------------------------------------
  send_buttons
------------------------------------------------------------------------------*/

bool send_buttons(bool white, bool blue) {
  /* Send out new button states to the web server.
  Returns true when successful, otherwise false.
   */
  display.clearDisplay();
  display.setCursor(0, 0);
  display.println(F("Sending..."));
  display.display();

  char expected_reply[4];
  snprintf(expected_reply, 4, "%d %d", white, blue);
  http_request = F("key=");
  http_request += mac_address;
  http_request += F("&white=");
  http_request += white;
  http_request += F("&blue=");
  http_request += blue;
  bool success = http_post(url_button_pressed, http_request, expected_reply);

  screensaver.engage(success ? 1e3 : 30e3);
  return success;
}

/*------------------------------------------------------------------------------
  setup
------------------------------------------------------------------------------*/
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
void loop() {
  char *strCmd; // Incoming serial command string

  // Check physical buttons
  switch_white.poll();
  if (switch_white.pushed()) {
    request_LED_white = !state_LED_white;
  }

  switch_blue.poll();
  if (switch_blue.pushed()) {
    request_LED_blue = !state_LED_blue;
  }

  // Check for incoming serial commands used for debugging
  if (sc.available()) {
    strCmd = sc.getCmd();

    if (strcmp(strCmd, "w") == 0) {
      request_LED_white = !state_LED_white;

    } else if (strcmp(strCmd, "b") == 0) {
      request_LED_blue = !state_LED_blue;

    } else if (strcmp(strCmd, "e") == 0) {
      send_email();

    } else if (strcmp(strCmd, "s") == 0) {
      send_starting_up();

    } else if (strcmp(strCmd, "?") == 0) {
      Ser.print(state_LED_white);
      Ser.print(" ");
      Ser.print(state_LED_blue);
      Ser.println("\n");
    }
  }

  // Did anything change?
  if (request_LED_white != state_LED_white) {
    write_LED_white(request_LED_white);
    Ser.println(F("WHITE\n-----"));
    request_is_pending = true;
  }

  if (request_LED_blue != state_LED_blue) {
    write_LED_blue(request_LED_blue);
    Ser.println(F("BLUE\n-----"));
    request_is_pending = true;
  }

  if (request_is_pending) {
    // Send out new states to the web server
    if (send_buttons(request_LED_white, request_LED_blue)) {
      // Success -> Grant request
      state_LED_white = request_LED_white;
      state_LED_blue = request_LED_blue;
      email_scheduler.bump();
    }
    write_LED_white(state_LED_white);
    write_LED_blue(state_LED_blue);

    // Reset pending request
    request_is_pending = false;
    request_LED_white = state_LED_white;
    request_LED_blue = state_LED_blue;
  }

  // The ESP8266 mcu has a lot of background processes (WiFi connectivity and
  // streams) that must get computing time without too much long delays in
  // between. This is critical to prevent a possible crash and reset of
  // the ESP8266. Hence, we must yield to these processes frequently.
  // yield();
  // EDIT: `delay()` gets redefined by the ESP8266 library to include a call to
  // `yield()` -- actually, `esp_yield()`. Several sources on the internet state
  // that their projects work better when calling `delay(1)` instead of straight
  // `yield()`.
  delay(1);

  screensaver.update();
  if (email_scheduler.poll()) {
    send_email();

    // v2.0: After the automated 'Chemicals delivered' email has been send to
    // the user, revert all buttons back to their idle off state. The user no
    // longer has to deactivate any lit buttons, and hence the 'All done' email
    // message is now suppressed.
    request_LED_white = false;
    request_LED_blue = false;
    state_LED_white = false;
    state_LED_blue = false;
    write_LED_white(false);
    write_LED_blue(false);
    send_buttons(false, false);
    email_scheduler.reset();
  }
}

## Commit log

2021-10-28 Implemented hot-reload webpage whenever button press is registered
2021-10-29 Send out button states to the server at boot
2021-11-11 Added status 'arduino_starting_up`. Changed `button status` to `Arduino status`.
2021-11-11 Fixed missing Arduino status in email
2021-11-11 Improved `Arduino starting up` signal to web server
2021-11-11 `send`-functions now return void, instead of boolean. `infinite_loop()` now also prints to serial.
2021-11-12 Update Switch from v1.2.1 to v1.2.4
2021-11-12 TODO: LEDs should get permanent state when state-change request is granted by web server
2021-11-15 LEDs get permanent state when state-change request is granted by web server.
2021-11-15 `send_starting_up()` now resets LEDs as well
    [main.cpp]
2021-11-22 Solidworks 2021
    [12mm flat Round head Waterproof Momentary Latching Metal Push Button Switch v11.SLDASM, 12mm flat Round head Waterproof Momentary Latching Metal Push Button Sw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]
2021-11-24 Conform Solidworks repo
    [2890 Doubler FeatherWing.SLDPRT, 2900 Feather OLED Wing.SLDPRT, OLED_screen_in_tray.SLDASM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]
2021-11-25 Now making use of Solidworks repository
    [12mm flat Round head Waterproof Momentary Latching Metal Push Button Switch v11.SLDASM, 2890 Doubler FeatherWing.SLDPRT, 2900 Feather OLED Wing.SLDPRT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]
2024-11-06 User no longer needs to reset buttons manually. Suppressed 'All done' email message.
    [main.cpp]
2025-02-13 Using Symfony Framework to send out emails, instead of PHP `mail()`
2025-02-13 Keep track of the last sent email and print this info to the webpage.
